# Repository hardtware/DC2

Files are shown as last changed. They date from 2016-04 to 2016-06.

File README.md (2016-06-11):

# DC2 Setup

0. [Unpacking your DC2](#0-unpacking-your-dc2)
1. [Power up your DC2](#1-power-up-your-dc2)
2. [Find the DC2 on your network](#2-find-the-dc2-on-your-network)
3. [Configure the DC2](#3-configure-the-dc2)
4. [Add the DC2 as a docker machine](#4-setup-dc2-as-a-docker-machine)
5. [Assemble the DC2](#5-dc2-assembly)
6. [FAQ](#6-faq)

## 0. Unpacking your DC2

- The first time you open the container doors, be really careful. The container is a model and was not designed to be an enclosure. If a hinge breaks, you can set it aside. If you have success gluing your hing back on, please share.

- We booted all of the MinnowBoard Turbots to make sure they would cleanly boot. See the FAQ below if your MinnowBoard does not boot up.

## 1. Power up your DC2

1. Let's make sure your MinnowBoard boots up and get it all setup while we can easily see the lights etc. before putting it in the container. If you have more than one DC2, let's set them up separately.

2. Set your MinnowBoard on the pink foam to protect it from shorting out.

3. Connect your USB drive to the MinnowBoard. Plug it into the USB socket that is blue.

4. Connect your MinnowBoard with an ethernet cable to the same network your PC that you will use to setup the DC2 is connected to.

5. OPTIONALLY connect your MinnowBoard to a display with a micro HDMI connector.

6. The last connection will be connecting your MinnowBoard to power.

7. You should see the USB drive light flicker. If you have an display connected, you should see the the boot sequence scroll across.

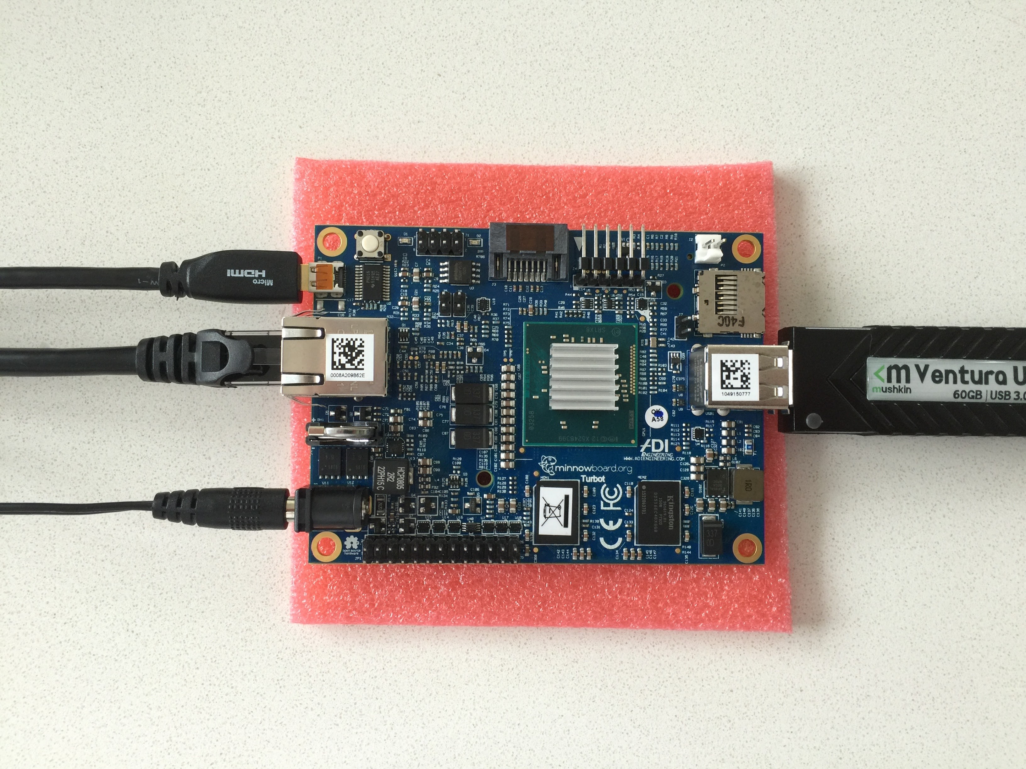
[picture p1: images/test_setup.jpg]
test setup
    

## 2. Find the DC2 on your network

1. Make sure you have Bonjour / mDNS.

    When you connect your DC2 to your network, it will be using DHCP to get an IP address. To work with the DC2 from other machines, we will need to find out where it is. The DC2 will default to having the '''dc2.local''' hostname which will be broadcast with mDNS aka Bonjour. If you have a Mac or Windows 10 machine, you are good to go. If you have an earlier version of Windows, you will need to install [Bonjour Services](https://support.apple.com/kb/DL999?viewlocale=en_US&locale=en_US), If you are on a linux box, you can install [Avahi](https://wiki.archlinux.org/index.php/Avahi).

2. If you have more than one DC2, then set them up one at a time so you can change the host names to differentiate between them.

3. Check you can connect to your DC2.

    Open up [http://DC2.local:8765](http://DC2.local:8765) with your browser -- this should return the configuration information from your DC2.

    It can take 40 seconds for the DC2 to boot, and 30 seconds for the dc2-node script to run and Bonjour to have completed its broadcast so that loading the web page to work. You should see something like this:

    ```json
    {
        "latestVersion": "1.0.4",
        "version": "1.0.4",
        "hostname": "dc2",
        "ip": "a.b.c.d",
        "MAC": "ff:ff:ff:ff:ff:ff",
        "callHomeResponse": 200
    }
    ```

    Where `a.b.c.d` is the IP address of your DC2 and `ff:ff:ff:ff:ff:ff` is the MAC address of your DC2 ethernet port.

## 3. Configure the DC2

1. Check that you can SSH into your DC2.

    - `username`: `jack` is the preconfigured username
    - `password`: `hardtware` is the preconfigured password

    ```shell
    ssh jack@dc2.local
    ```

2. Change your password

    ```shell
    passwd
    ```

    Enter `hardtware` for the old password, and then enter your new password.

3. If you don't have an ssh key, on *another* machine run the following:

    ```shell
    ssh-keygen -b 4096 -f ~/.ssh/id_rsa.dc2
    ```

    You will be prompted to create a passphrase, create one and enter it in twice as prompted.

4. Copy your SSH public key to your DC2.

    First `exit` your SSH session with your DC2.

    If your SSH public key is at `~/.ssh/id_rsa.pub` (if created above, use `~/.ssh/id_rsa.dc2`) then from your machine:

    ```shell
    ssh jack@dc2.local "cat >> .ssh/authorized_keys" < ~/.ssh/id_rsa.pub
    ```

    Enter your new password when prompted.

    You should now be able to `ssh jack@dc2.local` and not be prompted for a password.

5. If you are not in the `America/Los Angeles` timezone you can change it with:

    ```shell
    sudo dpkg-reconfigure tzdata
    ```

6. If you want to change the locale, follow directions at [https://help.ubuntu.com/community/Locale](https://help.ubuntu.com/community/Locale).

7. If you have more than one DC2, change your hostname by replacing `dc2` to a new hostname unique on your network (eg. dc2a, dc2b, dc2c) in the `/etc/hostname` and `/etc/hosts` files.

    For example, if you wanted to change the hostname to `dc2a`, you would run:

    ```shell
    sudo echo dc2a /etc/hostname
    sudo sed -i 's/dc2/dc2a/1' /etc/hosts
    ```

    Then restart `hostname` and `avahi` services with:

    ```shell
    sudo service hostname restart
    sudo /etc/init.d/avahi-daemon restart
    ```

    > NOTE: Everwhere you see `dc2` below, change that to the new hostname you have given your DC2.

8. OPTIONALLY change the username from `jack` to something else. This requires a few more commands and should be considered a bit more advnaced of a topic.

    In our example we will change the username to `bob` and remove `jack` entirely. For this example, start my being logged in as `jack`.

    Create the new user:

    ```shell
    sudo useradd -m bob
    ```

    Set a `sudo` password for the user:

    ```shell
    sudo passwd bob
    ```

    Create the `ssh` directory for the user:

    ```shell
    sudo mkdir /home/bob/.ssh
    sudo chown bob:bob /home/bob/.ssh
    sudo chmod 700 /home/bob/.ssh
    ```

    If you created and copied over a ssh key for jack, let's copy it over to bob.

    ```shell
    sudo cp /home/jack/.ssh/authorized_keys /home/bob/.ssh/authorized_keys
    sudo chown bob:bob /home/bob/.ssh/authorized_keys
    ```

    The last item is to add `bob` to all of the appropriate groups that `jack` is a member of:

    ```shell
    sudo usermod -a -G adm bob
    sudo usermod -a -G cdrom bob
    sudo usermod -a -G sudo bob
    sudo usermod -a -G dip bob
    sudo usermod -a -G plugdev bob
    sudo usermod -a -G lpadmin bob
    sudo usermod -a -G dc2 bob
    sudo usermod -a -G sambashare bob
    ```

    In a new terminal window, try to SSH now as bob using pubkey auth:

    ```shell
    ssh -o IdentityFile=~/.ssh/id_rsa bob@dc2.local
    ```

    > NOTE: You will need to change `~/.ssh/id_rsa` to your respective key path from above and `dc2.local` to whatever you changed your hostname to above as well.

    If you are able to SSH in at this point you have correctly created another user and setup their SSH key correctly.

    As the final step, you may remove the `jack` user from the device.

    ```shell
    sudo userdel -r jack
    ```

9. OPTIONALLY disable password authentication and only allow pubkey authentication. This is recommended for most users but is considered optional because it is more advanced.

    Bring up `/etc/ssh/sshd_config` in your favorite editor and uncomment the line that has `PasswordAuthentication`. Change the value to `no` if it is not set as such.

    Once completed, run:

    ```shell
    sudo service ssh restart
    ```

10. OPTIONALLY update your packages.

    Run:

    ```shell
    sudo apt-get update
    sudo apt-get upgrade
    ```

    You may need to enter `y` to approve the updates.

## 4. Setup DC2 as a Docker Machine

1. Make sure you have the [Docker Toolbox](https://www.docker.com/products/docker-toolbox) intalled on your computer.

2. Find the IP address of your DC2:

    ```shell
    ping dc2.local
    ```

    Substitute `a.b.c.d` in the following commands with your DC2's IP address

3. Check that you can use SSH against your IP address:

    ```shell
    ssh dc2@a.b.c.d
    ```

   If you had previously used SSH against that IP address, your will likely get an error and you will need to update your `known_hosts` file.

4. Add your SSH key to your agent.

    ```shell
    ssh-add ~/.ssh/id_rsa
    ```

    You will be prompted for your SSH key passphrase. You may need to change `~/.ssh/id_rsa` to the path of your key that you created.

5. OPTIONALLY create a separate user to run `docker`. This is a security measure.

    On the DC2, create a user and password for the user:

    ```shell
    sudo useradd -m dockeradmin
    sudo passwd dockeradmin
    sudo mkdir /home/dockeradmin/.ssh
    sudo chown dockeradmin:dockeradmin /home/dockeradmin/.ssh
    sudo chmod 700 /home/dockeradmin/.ssh
    ```

    Back on your machine, create a SSH key and copy it to the DC2. Make sure *not* to enter a passphrase for this user, unlike your SSH key pair which most certainly should have a passphrase.

    ```shell
    ssh-keygen -b 4096 -f ~/.ssh/id_rsa.dc2.docker
    ```

    With your favorite editor, create `/home/dockeradmin/.ssh/authrorized_keys` to contain the public half of the keypair (`~/.ssh/id_rsa.dc2.docker.pub`). And make sure to set the proper permissions:

    ```shell
    sudo chown dockeradmin:dockeradmin /home/dockeradmin/.ssh/authorized_keys
    sudo chmod 600 /home/dockeradmin/.ssh/authorized_keys
    ```

    Give the ability to this user full `sudo` access:

    ```shell
    sudo visudo
    ```

    Copy/paste the following towards the bottom after the `%sudo` definition:

    ```shell
    # Docker
    dockeradmin     ALL=(ALL) NOPASSWD: ALL
    ```

    If everything was done perfectly, you should now be able to SSH as this user to the DC2.

    ```shell
    ssh -o IdentityFile=~/.ssh/id_rsa.dc2.docker dockeradmin@a.b.c.d
    ```

6. Setup the DC2 as a generic machine:

    ```shell
    docker-machine create --driver generic --generic-ssh-user=jack --generic-ip-address=a.b.c.d dc2
    ```

    You may need to change the username if you created a separate one above. This command takes a while as it will be updating the DC2. It will create add your DC2 as a machine to run containers in. Sometimes `docker-machine` emits an error about certs.

    An example successful command and output might look like the following (with a couple more options):

    ```shell
    docker-machine create --driver generic --generic-ssh-user dockeradmin --generic-ssh-key ~/.ssh/id_rsa.dc2.docker --generic-ip-address 10.1.12.2 --generic-ssh-port 22 dc2
    ```

    ```
    Running pre-create checks...
    Creating machine...
    (dc2) Importing SSH key...
    Waiting for machine to be running, this may take a few minutes...
    Detecting operating system of created instance...
    Waiting for SSH to be available...
    Detecting the provisioner...
    Provisioning with ubuntu(upstart)...
    Installing Docker...
    Copying certs to the local machine directory...
    Copying certs to the remote machine...
    Setting Docker configuration on the remote daemon...
    Checking connection to Docker...
    Docker is up and running!
    To see how to connect your Docker Client to the Docker Engine running on this virtual machine, run: docker-machine env dc2
    ```

7. Check the status of your DC2 docker machine:

    ```shell
    docker-machine status dc2
    ```

    It should state `Running` at this point.

8. Setup the DC2 as your docker machine:

    To view the environment for your docker machine:

    ```shell
    docker-machine env dc2
    ```

    It should output several lines.

    For assistance with this or any `docker` command you can always run `docker-machine help <command>`.

    Where command can be `env` or any other `docker-machine` command.

9. Run the hello-world container:

    First, you need to setup your local environment by running the above `env` command. The output of that command at the end should have something like:

    ```shell
    # Run this command to configure your shell:
    # eval $(docker-machine env dc2)
    ```

    Run the `eval ...` command.

    After that, run:

    ```shell
    docker run hello-world
    ```

    You should see "Hello from Docker" along with various other output. You now have a functining Desktop Computer Container!

10. Shutting down your DC2. Make sure you properly shutdown your DC2 so that the file system does not get corrupted. If it does, you will need to connect a monitor and keyboard to fix the errors on boot.

    ```shell
    ssh jack@dc2.local
    sudo shutdown -h now
    ```

    Success! Disconnect power, ethernet and HDMI (if connected) and finish assembly.

## 5. DC2 Assembly

1. Connect the MinnowBoard Turbot to the faceplate.

    1. Get a #1 (or #2 if need be) philips head screwdriver and screw the 2 M3 philips screws each in a few turns. You want the screws to go in from the left side if you are looking at the front of the faceplate. We are doing this to loosen the threads as the faceplate threads are 3D printed.

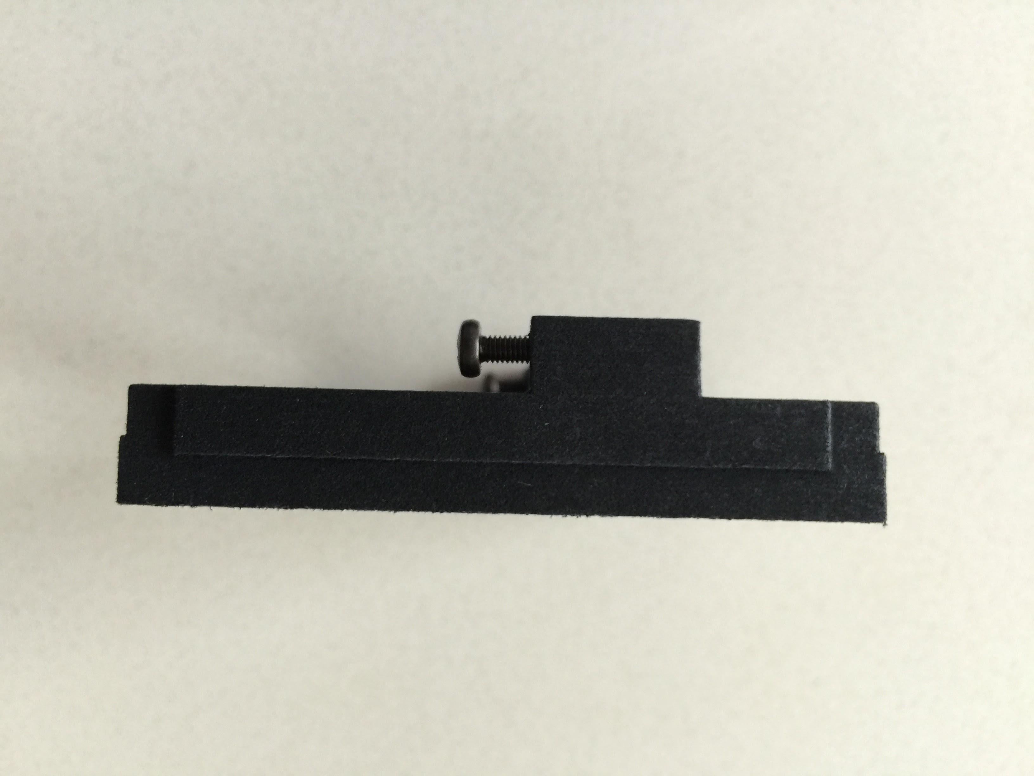
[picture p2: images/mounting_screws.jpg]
mounting screws
        

    2. Take out the screws, set the MinnowBoard Turbot on the faceplate, and screw the screws back in. Tighten enough that the MinnowBoard Turbot does not wobble around on the faceplate. If you have ordered a SilverJaw Lure, you can first mount it to the MinnowBoard Turbot placing the spacers between the two boards, then screw the screws into the faceplate, and then screw the screws into the standoff at the other end of the boards.

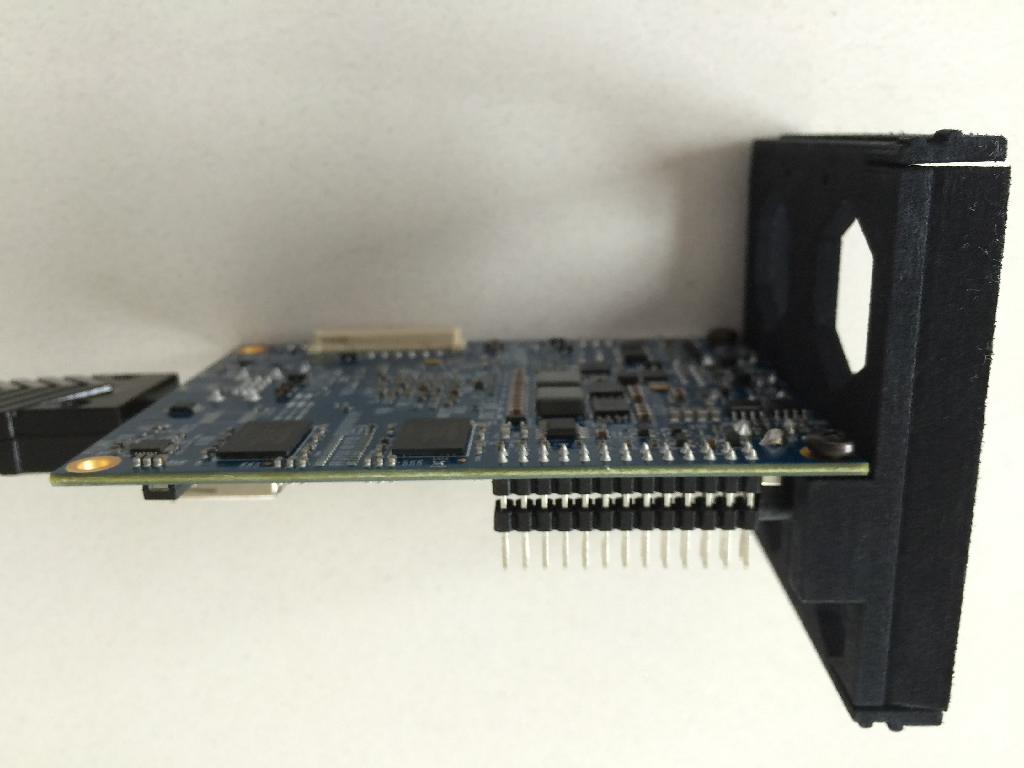
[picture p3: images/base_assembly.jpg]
        

        With SilverJaw

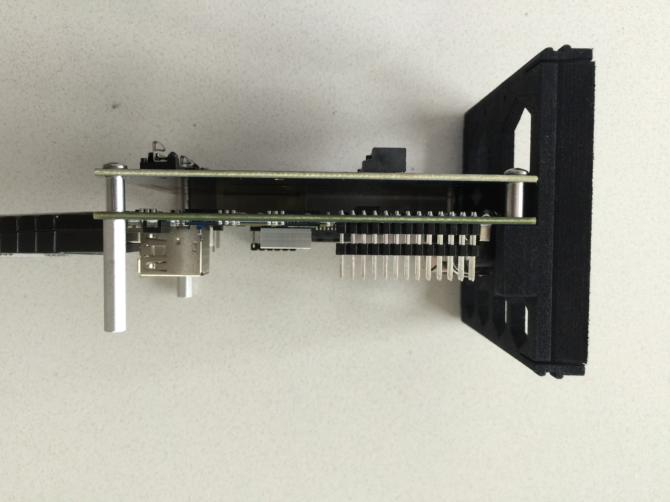
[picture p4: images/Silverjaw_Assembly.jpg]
        

2. Connnect the USB drive to the MinnowBoard if it is not connected.

3. If you have an OLED you need to connect it before installing the MinnowBoard Turbot into the container.

    1. Just as we did with the screws for mounting the MinnowBoard, we need to clean out the threads for the OLED mount. Screw the M1.6 screws into the OLED mounting locations with the supplied allen wrench, and then take them back out.

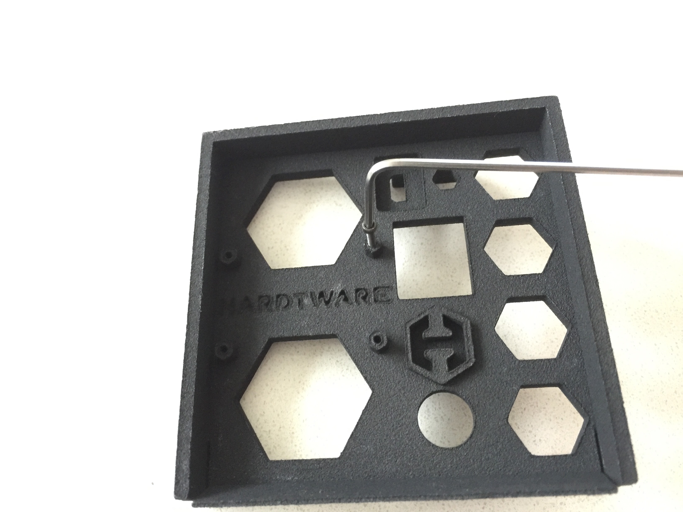
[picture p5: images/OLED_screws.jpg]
mounting screws
        

    2. Insert the memory card into the OLED. This image also shows how the cable will be connected.

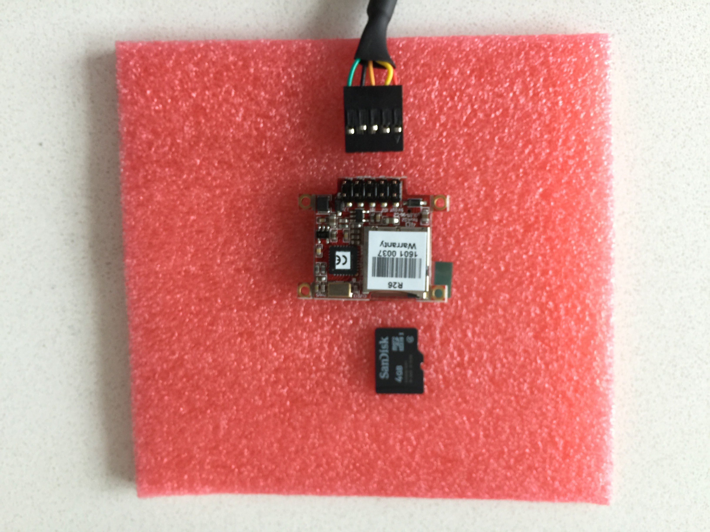
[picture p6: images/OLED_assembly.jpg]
        

    3. Mount the OLED with the 4 M1.6 hex head screws.

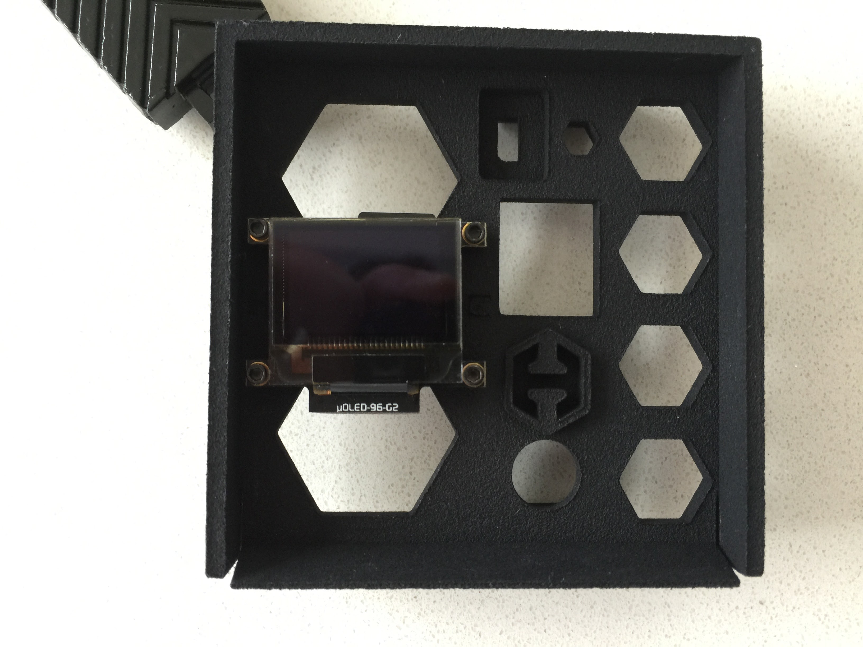
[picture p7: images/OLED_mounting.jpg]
mounting screws
        

    4. Connect the cable from the USB 2.0 connector to the OLED. Make sure you connect per the image and then coil the cable as indicated. You can use the twist tie from the power supply to hold the OLED cable.

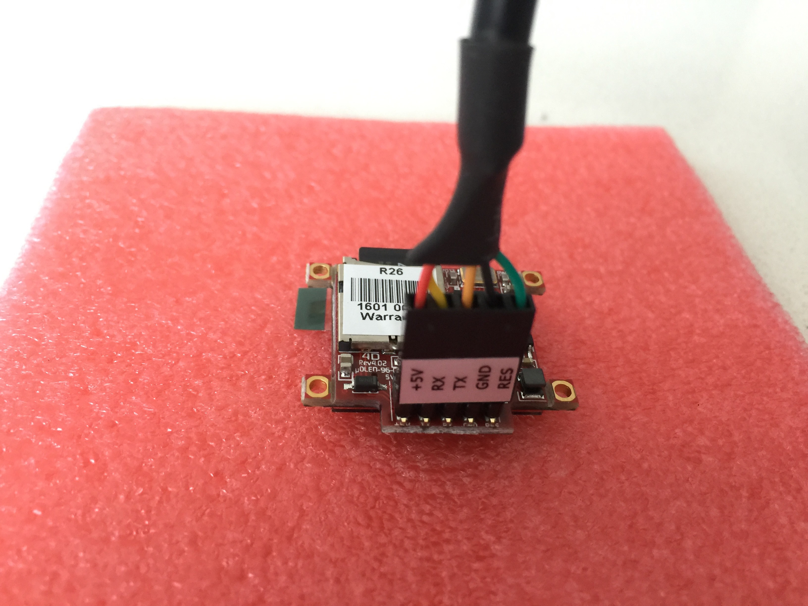
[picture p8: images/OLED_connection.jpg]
        

        Full Assembly

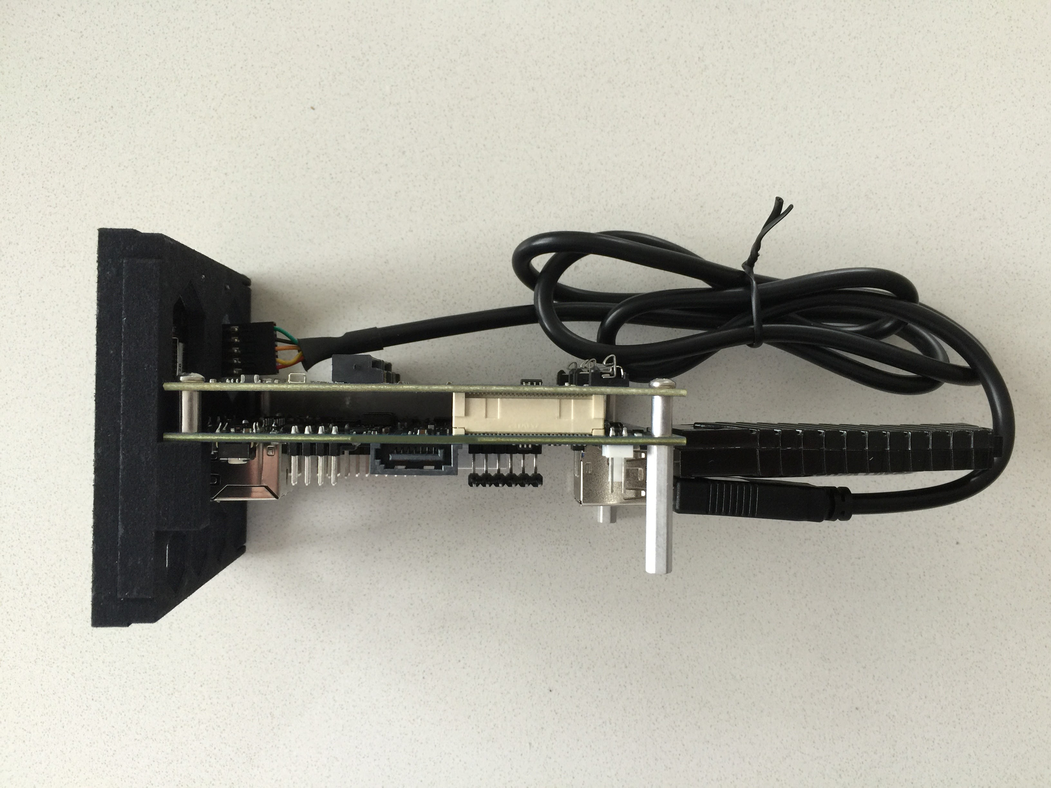
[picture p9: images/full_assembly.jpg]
        

    5. NOTE: we are still working on software to drive the OLED.

4. Slide the assembled MinnoBoard and faceplate into the container. It should click a little when fully installed.

6. Reconnect ethernet and power and enjoy your DC2!

## 6. FAQ

1. **Question**: Something is not working?

    **Answer**: Check the FAQ below. If not answered, file an issue at https://github.com/hardtware/DC2/issues

2. **Question**: What is the CR1225 battery for?

    **Answer**: It is a spare battery. Your MinnowBoard Turbot should have a CR1225 battery in it already.

3. **Question**: I see `WRITE SAME failed. Manually zeroing.` on boot. What is happening?

    **Answer**: You don't need to worry about this and can ignore it. If you would like to make this message go away since it is unrelated to this hardware (it has to do with SCSI driver which is irrelevant for us), you can! Copy the following script to `/usr/local/sbin/disable-write-same`:

    ```shell
    #! /bin/sh
    # Disable SCSI WRITE_SAME, which is not supported by underlying disk
    # emulation.  Run on boot from, eg, /etc/rc.local
    #
    # See http://www.it3.be/2013/10/16/write-same-failed/
    #
    # Written by Ewen McNeill <ewen@naos.co.nz>, 2014-07-17
    #---------------------------------------------------------------------------

    find /sys/devices -name max_write_same_blocks |
        while read DISK; do
            echo 0 >"${DISK}"
        done
    ```

    And then add a call on boot to this script before the `exit` in `/etc/rc.local`.

    On reboot you should no longer see this message.

    Source [link](http://ewen.mcneill.gen.nz/blog/entry/2014-07-17-mininet-on-ubuntu-14.04-in-kvm/).

4. **Question**: The machine did not boot. What happened?

    **Answer**: Sometimes something gets out of sync somewhere with the onboard memory and the drive and Ubuntu thinks something is corrupted and you have to tell it to continue. If you have a display attached you can see it. You can just hit `i` to ignore and everything will be fine. You might need to hit `i` a few times. If you don't have a monitor, try connecting a USB keyboard and hit `i` a few times. If you see the drive light flash, you should be booting.

5. **Question**: How do I remove the faceplate once I have assmebled it?

    **Answer**: To take out the faceplate and the board, put your fingers in the large hex holes, push the faceplate down towards the bottom of the container as the top of the faceplate hooks to the top inside of the container, then wiggle and pull to get it out.

6. **Question**: How can I stack up my containers?

    **Answer**: [remonlam](https://github.com/remonlam) has created an STL you can 3D print to stack up your containers [here](./stacker.md)

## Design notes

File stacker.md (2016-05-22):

# DC2 Stacker

... thanks to [remonlam](https://github.com/remonlam)

The Kickstarter backers that have bought the DC2 Data Center (a stack of 4 containers) might have a hard time to get them stacked.
This is because there's no lock to get the containers nicely stacked. To make sure they keep "stacked" on top of each other I created a small frame called the "DC2 Stacker" :-)

All you need to do is print (a 3D printer that is, not you're regular printer) the [STL file](./sources/dc2_stacker.stl) three (3x) times. One would be the base layer, and the two other layers should be glued together (with superglue) to form the mid section.

The end result should look like this;

#### Place the layer on top of the fist two containers
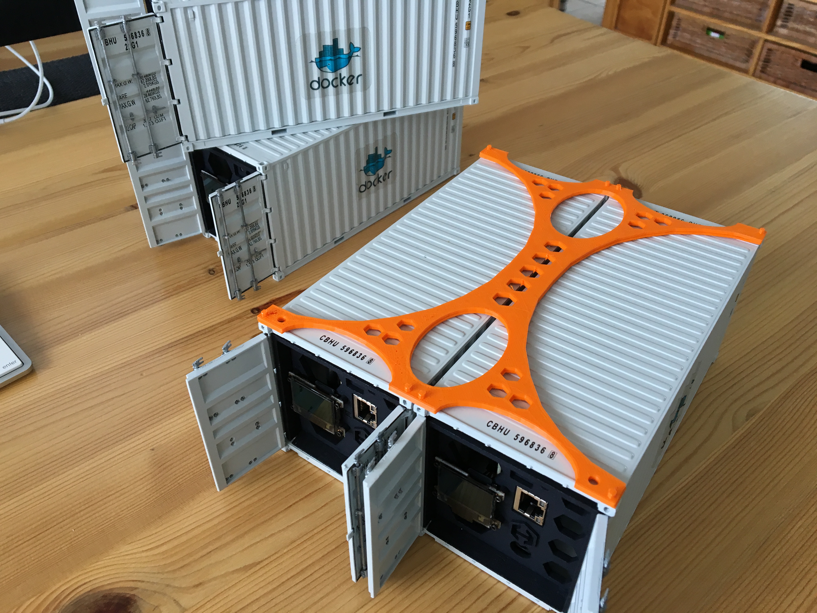
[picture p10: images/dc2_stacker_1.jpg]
Two layers glued together


#### The next layer of containers should fit in nicely
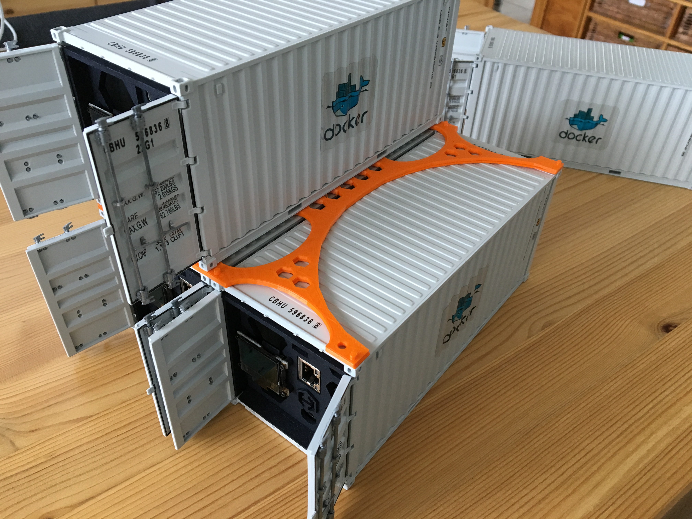
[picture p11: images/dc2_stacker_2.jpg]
Build the stack


#### The end result, now the containers won't fall off the stack
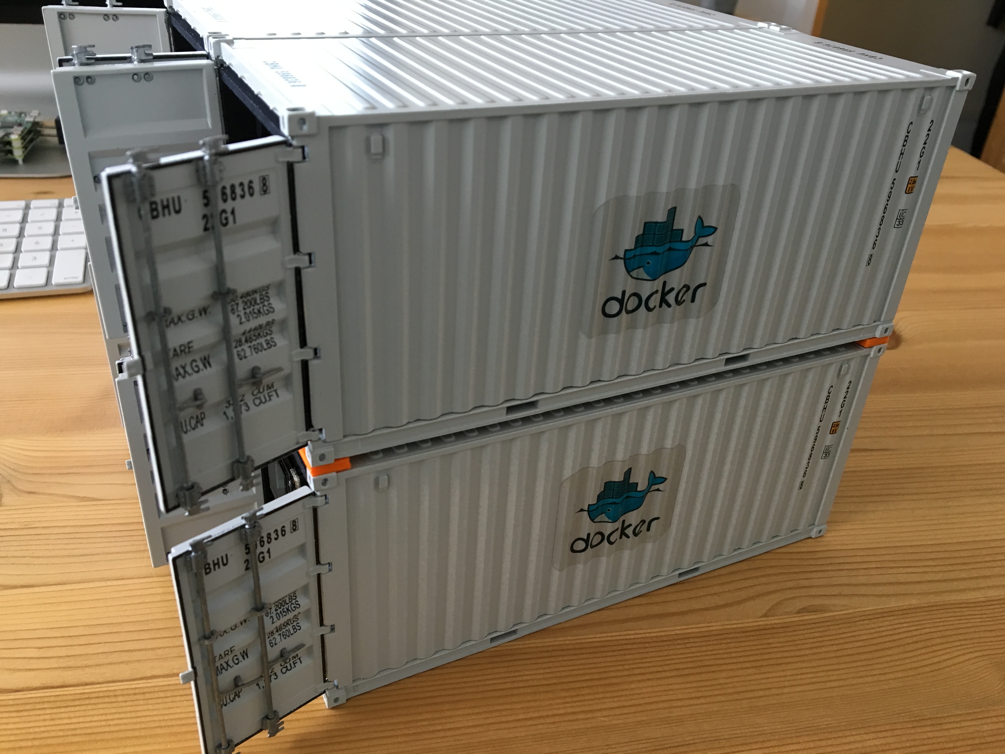
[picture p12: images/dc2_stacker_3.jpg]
End result 1

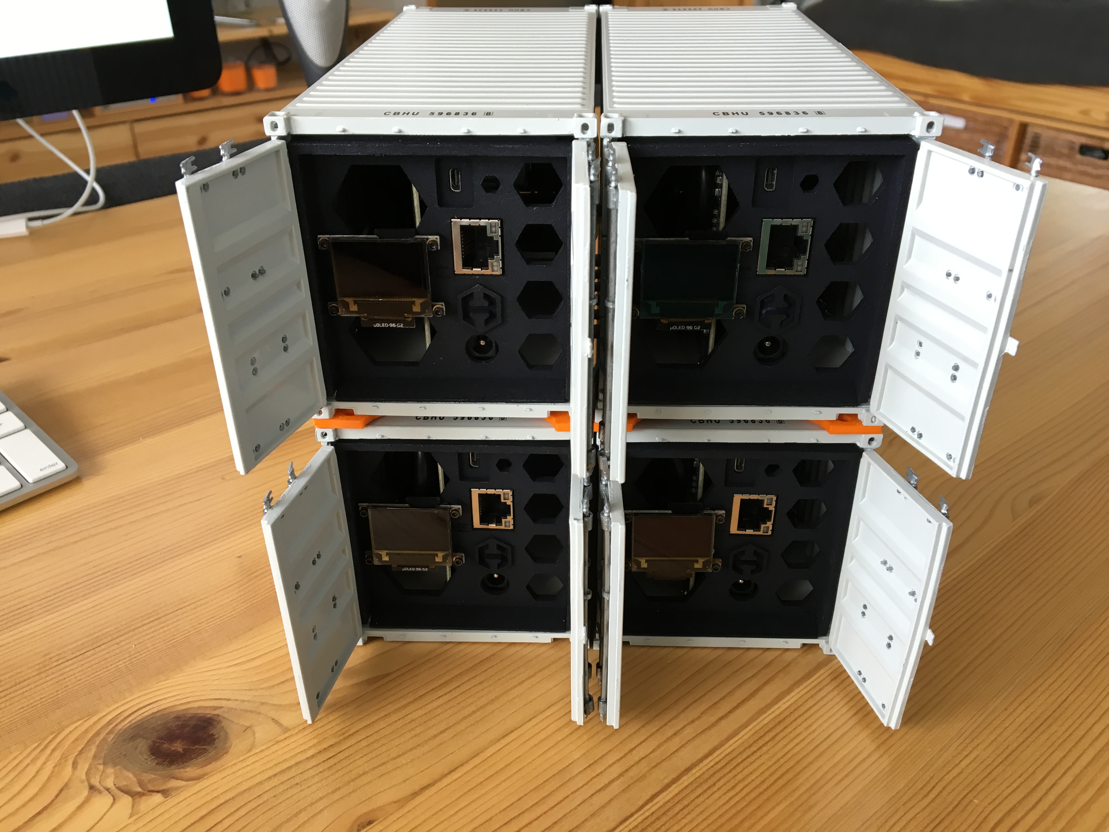
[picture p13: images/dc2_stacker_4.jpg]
End result 2


#### STL file
[DC2-Stacker STL file](./sources/dc2_stacker.stl)

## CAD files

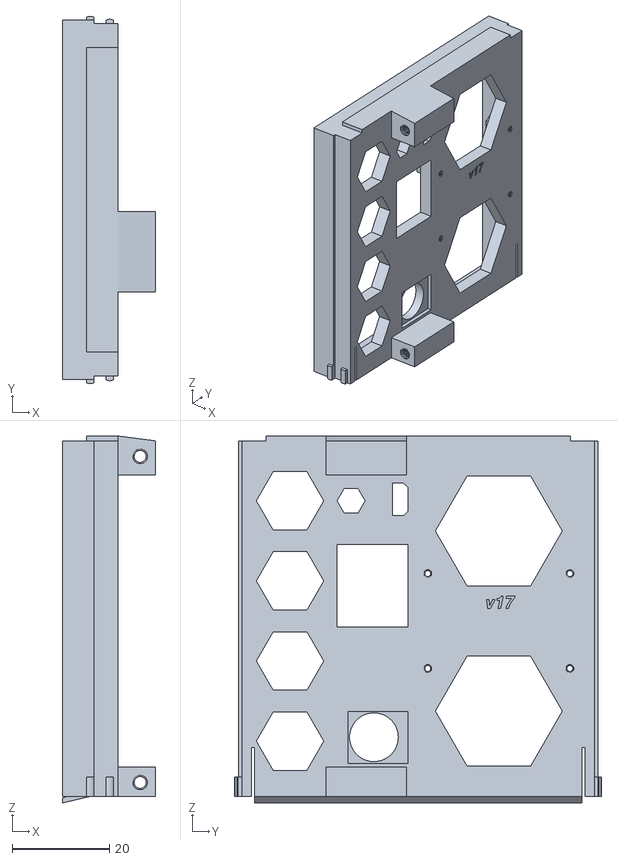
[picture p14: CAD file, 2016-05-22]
sources/FaceplateV17.stl
19.2 x 75.5 x 75.4

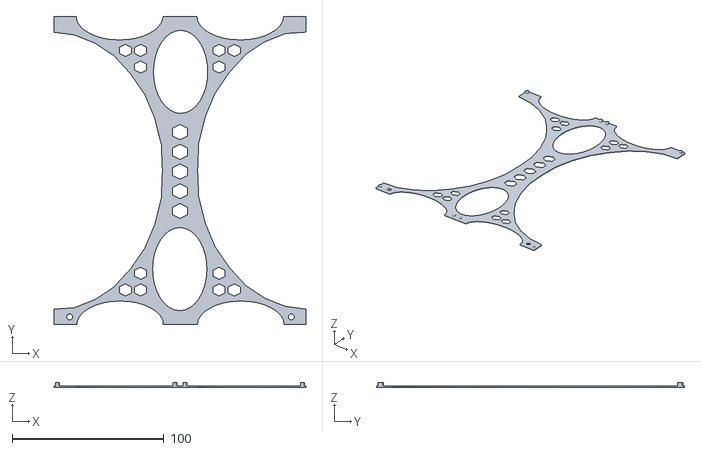
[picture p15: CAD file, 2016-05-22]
sources/dc2_stacker.stl
166.2 x 203.2 x 3.00

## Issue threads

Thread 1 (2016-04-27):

Accidentally broke doors of container off

Xe, 2016-04-27:
Is there any way I can get that repaired?

remonlam, 2016-04-28:
Can't you fix it with glue?

jlhawn, 2016-04-28:
Here's a picture of the first one that I opened. One of the hinges broke after opening the door about 45 degrees:

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

The other door opens just fine and swings out about 135 degrees. I don't want to open it any further than that.

> Can't you fix it with glue?

Is there a particular kind of glue that you recommend? I'm not 100% sure what kind of material this is. I remember reading somewhere that it was zinc.

dickhardt, 2016-04-28:
Unfortunately the doors hinges are fragile.
When opening the doors for the first time, one needs to be really carefully.
I'm sorry your door broke.

dickhardt, 2016-04-28:
I've updated the instructions to warn people.

jlhawn, 2016-04-28:
After trying again to carefully open the door, the top hinge popped off too.

It looks like the pin was misaligned the whole time so it probably never would have been able to open. You can see how it's pointing outward rather than parallel with the other hinges:

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

remonlam, 2016-04-28:
Whoops, that's not going to be fixed with superglue :-(
Not sure if you can solder zink?...

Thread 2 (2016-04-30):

DC2 doesn't connect to network

emdem, 2016-04-30:
The NICs lights light up but I can't see the MAC/etc connect to my network.

Only option is to get a microHDMI and connect to a monitor?

watkinspd, 2016-04-30:
What computer are you using make the ssh connection to dc2.local?

The instructions explain how dc2.local is using bonjour/avahi which makes the dc2.local hostname discoverable on your home network if the dc2 is booting and getting an address from DHCP.

If you are new to setting up and running machines "headless" I'd suggest making the investment in the hdmi cable (and USB connectable keyboard).

emdem, 2016-04-30:
I am using a touchpad S210 running mint (also tried another debian based distro) to connect to dc2.local. My router provides DHCP and when I check, I can see all the MAC addresses/IPs/hostnames of machines I already have but when the DC2 is turned on and connected, nothing. Hard drive light/etc are all on.

remonlam, 2016-05-01:
So just to be clear; you don't see any IP address assignment on your router when you turn on the DC2?
If not perhaps it's easier for troubleshooting to connect an monitor to the minnowboard and check what's going on.

rloura, 2016-05-03:
Same issue as above.  I don't see it show up on the local network, and have not yet sourced an HDMI adapter to see what is going on.

ikenichiro, 2016-05-04:
I'm having the same issue.
As far as I see through the syslog on my network, connections between DC-2 and other hardware seems to be OK, but I get nothing from the DHCP server.
I've ordered the micro-HDMI cable which I should have it by tommorow, and try to see what's going on.

ikenichiro, 2016-05-04:
Solved my issue by connecting a USB keyboard and pressing the button **i** for a few times during the boot. After a few seconds, I got a successful syslog message from the DHCP server. I checked SSH connection (through direct IP address instead of dc2.local ) and it works perfectly.

Since I'm not a linux expert, I couldn't determine what the main cause was, but from the dmesg I see
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
which I suspect might be where the boot might be halting.

I'll also note that maybe this problem occures only at the first boot. Currently I have no problems restarting the system and booting after a shutdown (detaching the power cable for few minutes).

Although, I will try to reproduce the problem after the micro-HDMI cable arrives to see what might be the problem is.

remonlam, 2016-05-04:
@ikenichiro sounds like there's something wrong with the filesystem or at least that's what the system thinks ;-) did you check what date/time the machine had on the first boot?

I had the same issue with my MinnowBoard Max (the old one without a RTC) and CoreOS from time to time the system failed to boot and I needed to force a FS check to get the system up and running again.

Can't check because my DC2 is still at the customs :-( but there should be a RTC on the system, right?
If so than it should keep the correct time even without a power source, maybe you could check this out?

ikenichiro, 2016-05-04:
@remonlam I actually did check it.
According to DC2's syslog, the date/time when syslog started on my first boot was set to Nov 22 13:04:40. Before that was Mar 24 16:02:45 .
> Mar 24 16:02:45 dc2 rsyslogd: [origin software="rsyslogd" swVersion="7.4.4" x-pid="845" x-info="http://www.rsyslog.com"] exiting on signal 15.
> Nov 22 13:04:40 dc2 rsyslogd: [origin software="rsyslogd" swVersion="7.4.4" x-pid="839" x-info="http://www.rsyslog.com"] start
(snip)
> Nov 22 13:04:50 dc2 NetworkManager[809]: <info> WiFi hardware radio set enabled
> May 4 11:29:00 dc2 ntpdate[1258]: step time server 91.189.89.199 offset 14160245.250085 sec

And yes, there is an RTC on the system so it does keeps the correct time without a power souce ( I confirmed this by log file as also).
For trying to reproduce the problem, I am planning to do it with removing the battery on the MinnowBoard which should atleast give some clues to whether the problem is actually in the filesystem or looks like that because of the corrupted system time.

hbokh, 2016-05-05:
See #4. I managed to boot from the USB-drive within Virtualbox, set an easy root password and do some debugging.
My DC2 gets an IP-address from my DHCP-server but remains unreachable eg.
The DC2 is booting OK and I can login as root and type some commands "blind".
Booting from DC2 and typing blind `ifconfig -a > file1` and `netstat -rn > file2`.
Next shutting down the DC2 and boot from the USB-drive within Virtualbox so I can read `file1` and `file2` to see what is there.
`file1` shows DC2 has gotten the IP-address my DHCP-server offered; `file2` shows the default gateway for `eth0`. Still the DC2 remained unreachable.
In the meantime I have disabled "network-manager" without result.

Any hints / clues / etc.?

remonlam, 2016-05-05:
@ikenichiro so it changed from March 24 to November 22 and back to the correct time (May 4), that couldn't be ok if it has a working RTC, I'm curious what will happend when you remove the RTC battery.

@hbokh Nice troubleshooting 👍 perhaps you could also try if the node can reach the Internet or your local machine, just a ping would probably do?

hbokh, 2016-05-05:
Everything is working in Virtualbox (incl. node), just not on the MinnowBoard...

In the meantime I have created a script to test all kinds of network related stuff when root logs in (set in `.profile`) and re-enabled network-manager.

/root/test:

```
#!/bin/sh

echo "===========================================================================================" > results
ifquery eth0 >> results
echo "===========================================================================================" >> results
ifconfig -a >> results
echo "===========================================================================================" >> results
ethtool eth0 >> results
echo "===========================================================================================" >> results
netstat -rn >> results
echo "===========================================================================================" >> results
nmcli nm >> results
nmcli d >> results
echo "===========================================================================================" >> results
ping -c3 192.168.178.1 >> results
echo "===========================================================================================" >> results
ping -c1 8.8.8.8 >> results
echo "===========================================================================================" >> results
ping -c1 google-public-dns-a.google.com >> results
```
Fails on the GW-ping at 192.168.178.1.
It seems the DC2 is never able to setup a connection to the default gateway, even when hard-coded with a fixed IP-address; netmask; gateway in `/etc/network/interfaces`.

hbokh, 2016-05-05:
So far I guess the issue is related to the Realtek interface / driver.
But I can't do any debugging anymore without installing a new OS since I kinda "briked" the USB-image with grub... Unless (as stated in #4) I can re-image the 60GB USB-drive from an image.
Until then, this by far the most expensive paper presse I have ever bought :(

remonlam, 2016-05-05:
That's a bummer :-(
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
ikenichiro, 2016-05-06:
Got my HDMI cable and a chance to look around a bit...
@remonlam I detached my power cable for quite a while, and had no problem with the RTC having the right time.
> May  4 14:45:00 dc2 rsyslogd: [origin software="rsyslogd" swVersion="7.4.4" x-pid="565" x-info="http://www.rsyslog.com"] exiting on signal 15.
> May  6 09:25:39 dc2 rsyslogd: [origin software="rsyslogd" swVersion="7.4.4" x-pid="571" x-info="http://www.rsyslog.com"] start

After taking off the battery and re-setting the RTC, I failed to boot a few times. Still not sure why since the display showed nothing.
Unplugging and plugging in the power a few times, I got it booting with display showing. Waited a few seconds to let the boot manager choose the default boot (which is Ubuntu).
The problem is, the moment it choose Ubuntu it showed an message something about an display error, telling it will try to boot showing nothing. The message quickly disappeared so I'll try to get that message next time I try.
Pressing a few i button after that message disappeared helped again, which let me able to login through SSH.
Checking the logs, the RTC had a reset as expected, but this time it was Sep. 17th.

> May  6 09:28:55 dc2 rsyslogd: [origin software="rsyslogd" swVersion="7.4.4" x-pid="571" x-info="http://www.rsyslog.com"] exiting on signal 15.
> Sep 17 17:02:27 dc2 rsyslogd: [origin software="rsyslogd" swVersion="7.4.4" x-pid="820" x-info="http://www.rsyslog.com"] start

I also found the same "EXT4-fs" erros in my syslog, which I'm assuming is caused by the incorrect time, and is the problem that is halting Ubuntu to boot.

hbokh, 2016-05-07:
@ikenichiro No offense, but your issue does not seems to be network-related (anymore).
"Unplugging and plugging in the power a few times" will only give you an unclean filesystem, hence the "EXT4-fs" errors. Incorrect time won't!
Try to shutdown gently if possible. You got a keyboard and display for that.

ikenichiro, 2016-05-08:
@hbokh The problem @emdem, @rloura and I was facing was a little bit different then yours. In your case, your board showed up in your local network (offered IP from DHCP) but in our case it does not. So originally it was thought that it was a network issue, but by trying things out, I'm thinking the cause is not a network issue. Since it is true this issue is going off topic as a "network-related" problem, making this post as my final post in this issue, I might make a different issue if it sill might be an issue to solve.

Last time I needed to unplug an plug the power a few times since I saw nothing on the display and the keyboard wasn't responding, but I completly forgot about the switch on the board near the hdmi interface. Might be slightly better using that switch rather than just unplugging the power.
Although, this time I didn't need to do any of that since the display and keyboard worked.
Still, the boot halts here.
> Starting userspace bootsplash     [OK]
ors were found while checking the disk drive for /boot.
s:Press F to sttempt to fix the errors, I to ignore, S to skip mounting, or M for manual recovery
Starting Send an event o indicate plymouth is up     [OK]
Stopping userspace  bootsplash      [OK]
Stopping Send an event to indicate plymouth is up      [OK]
Starting Bridge socket events into upstart      [OK]

Since it halt's before the nework configuration starts, that's why the device wasn't showing up in the network. Pressing i will let you continue to boot, and I think you will be able to see your DHCP server issuing an IP address to dc2.
So I think @remonlam was right about probably the system is thinking that the filesystem is corrupted which is caused by the wrong date/time.

Finally my answer to this issue is to get a usb keyboard and press i after waiting for a while ( one minute should be more than enough).
Probably this problem will only occur on your first boot incase the RTC had a reset (e.g. changing board battery).
The clock will sync through ntp after the first boot so you won't need to worry about this problem after one successful boot.

To actually solve the issue, forcing FS check on boot might solve the problem. I haven't tried this yet, but since now I know what's happening, I'm thinking to move on with the setup and think about this later.

dickhardt, 2016-05-20:
To confirm the suspicions, somehow the RTC gets confused, and then the OS thinks the file system is corrupt, but it is not. Any suggestions on how to have the OS ignore this error are welcome. We just have told the system to ignore the error and then it boots fine on subsequent boots.

We booted ALL the motherboards and then tested that they would boot again with no keyboard. Looks like that is not a permanent fix.

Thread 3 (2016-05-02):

DC2 can not connect to the network also

tsuitor, 2016-05-02:
I'm also having problems getting my DC2 seen on my network. However, the first time I booted it up, I apparently had an Ethernet cable that went bad. Right now I'm running it headless and using my iMac to try and connect.The board, network and SSD all show lights. Is there something else I can try before getting a mini HDMI cable (and probably a new Ethernet cable...). Thanks

remonlam, 2016-05-03:
I think there is already an issue related to this one. #2

josegonzalez, 2016-05-09:
You'll also need a keyboard. I found mine booted up and didn't connect because the usb stick needed to be "fixed" (aka I had to confirm that it was okay to fix).

tsuitor, 2016-05-09:
Okay, with a keyboard and display, I was able to get this to boot up and connect to the network; and mostly get docker running. However, now I'm getting the following error message when I try docker run:

docker: Error response from daemon: client is newer than server (client API version: 1.23, server API version: 1.22).

This is on a imac that I just installed docker toolbox last week. I'm guessing something is out of sync, but docker-machine upgrade dc2 doesn't seem to help.

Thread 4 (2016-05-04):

Non-reachable device - works in Virtualbox though

hbokh, 2016-05-04:
Received my DC2. My DHCP-server is offering an IP-address, but no PING response after over half an hour too.
I have no option to use a display, so plugged in a USB-keyboard and pressed `i` till my fingers bled. No luck...

Is there an image available to re-image the 60GB USB-drive?

**UPDATE, 12 hrs later**
Next, trying to boot from the USB-drive from within Virtualbox (HOWTO: http://www.sebastien-han.fr/blog/2013/12/16/virtualbox-mac-os-x-10-dot-9-boot-from-an-usb-drive/) and setting "Motherboard" to "Enable EFI" is working and gives me a VM. I can log in with user `jack` etc.

But why isn't it reachable on the network from the MinnowBoard? I'm still investigating.

hbokh, 2016-05-06:
Closed. See #2 for root cause.

Closed 2016-05-06.

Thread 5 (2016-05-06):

OLED doesn't work

emdem, 2016-05-06:

remonlam, 2016-05-08:
Well I have read somewhere that they are working on the code to get the OLED display working.

emdem, 2016-08-09:
anyone made any progress? if not, anyone have docs for the oled display and how to get code on the SD card?

emdem, 2016-08-09:
CP2102 USB to UART Bridge Controller driver + http://www.4dsystems.com.au/product/4D_Workshop_4_IDE/downloads?

emdem, 2017-10-30:
any updates? or anyone else successfully written some code for the oled?

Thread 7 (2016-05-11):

Boot failed

thepatrick, 2016-05-11:
After getting my MinnowBoard out of the container, and removing the USB stick I can boot to the UEFI/BIOS screen. However... when I reattach the USB stick the keyboard stops working inside the UEFI/BIOS interface. As soon as I disconnect it works again.

Now when I boot (with the USB stick attached) it gets through the memory check and then very quickly flashes Boot failed, before taking me to a UEFI interactive shell.

Do I:

* Have a faulty USB stick?
* Where is the image that these drives are flashed with so I can re-flash it / flash another drive to further debug this?

watkinspd, 2016-05-13:
While I was hacking around with building and booting sd-card images and other USB drives I noticed that sometimes it helped to use the Boot Manager option of the BIOS and the reset feature that was listed.
This seemed to cause the bios to re-scan for boot devices such that it would discover the sd-card or the USB drive and the drive partitions on it.

I've managed to get ubuntu, centos7, and coreOS booting on a different USB drive, and from sd-card.  To do this find the bare-metal install instructions for the linux distro you want to spin.  In my case I did not want to blast away the DC2 supplied USB drive image since I'm still hacking around and often landing in a non-bootable state.

I've still got lots of homework to do to learn how the BIOS works and how linux system drives are imaged and booted.

Right now I have the DC2 running centos7 and RedHat Openshift (kubernetes/docker) --- lots of fun.

dickhardt, 2016-05-13:
Some of the MinnowBoards are temperamental and don't always recognize the
USB devices. We found that with a number of boards. We did find that once
it was up and running, it was ok. I would guess that the USB drive and
keyboard are detected, or neither are detected.

Did you check if the USB drive is ok and that it will mount in another
device? We did have one USB that was DOA. If so, we can get you a new USB.

If the USB drive is ok, then I would try restarting a few times to see if
it starts to behave. If not, let's get you a new MinnowBoard.

On Fri, May 13, 2016 at 10:10 AM, Peter Watkins <notifications@github.com>
wrote:

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

--
Subscribe to the HARDTWARE <http://hardtware.com/> mail list to learn about
projects I am working on!

thepatrick, 2016-05-24:
I've dropped a Samsung m.2 SSD into my silver jaw lure & did a plain install of Ubuntu 16.04 server and have had no issues since.

Attempts at getting other devices to recognize the supplied USB stick - my windows pc & mac are both convinced there's nothing there (not even something that I can format)

dickhardt, 2016-05-24:
@thepatrick sorry your drive was DOA. We can send you a replacement.

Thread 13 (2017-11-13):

Ubuntu Rebuild Instructions

tyndyll, 2017-11-13:
I've had to replace the SSD. Is it possible to get instructions to rebuild a new disk?

remonlam, 2017-11-13:
I don't think that it has ever been published, however if you need a copy of the image? please let me know...

dickhardt, 2017-11-14:
Here are the directions I got from my friend that built the image

1. grab the ubuntu-desktop x86_64 14.04 LTS ISO
2. install it onto another usb drive, not the DC2 one, using one of the ubuntu USB media installers (either from w/in another ubuntu box, or there’s a windows media prep tool, or something else. http://www.ubuntu.com/download/desktop/create-a-usb-stick-on-ubuntu )
	** Note that step #2 was not easy, especially when I was using the ubuntu-server ISO instead of the desktop. Desktop ISO worked much better, but I’m not sure all the media prep programs on that page above are bug free. **

3. all defaults during the install, hostname is “dc2”, username is “dc2” i wrote down that the pw was “ubuntu” but I think you changed the default username and password. I enabled automatic security updates (again, I think this is probably the default setting).
4. this should set up a dhcp by default, I don’t think I enabled IPv6 or if I did I just left it as defaults
5. no special packages during install
6. On first boot my notes say I installed packages for docker and node. I don’t know if I needed to install the bonjour stuff (avahi-* packages) or if I was already enabled by default. I don’t know if I needed to enable docker or node to run on boot, but that would be another command to enable it on boot ( http://askubuntu.com/questions/9382/how-can-i-configure-a-service-to-run-at-startup explains).
7. I disabled the X11/graphical boot (using these instructions http://www.htpcbeginner.com/force-ubuntu-boot-into-terminal/ )
8. I manually updated all packages (“sudo apt-get update ; sudo apt-get upgrade ; sudo apt-get dist-upgrade ; sudo apt-get autoremove”) then reboot if it installed a new kernel, or if it says to reboot.
9. I probably installed the openssh-server package (“sudo apt-get install openssh-server”).
10. I did some checks on the permissions of the .ssh directory to make sure we’d be able to ssh in, then tested it from remote (“ssh dc2@dc2.local”).
11. I did some final cleanup (removing files I had created, .git dirs, .bash_history, etc… but this isn’t necessary unless you’re re-creating a new gold image).

tyndyll, 2018-01-16:
Finally got round to trying this. There seems to be something weird with the EFI boot - it seems like it is expecting a certain GUID for the disk (as set up in the boot options under the name ubuntu)

Would it be possible to get the original image

tyndyll, 2018-01-25:
@remonlam Would it be possible to get a copy of the image?

remonlam, 2018-01-25:
@tyndyll sure let me find a way to share it

remonlam, 2018-01-25:
Hope this one works!
https://we.tl/DnDh3lStUA

Closed 2017-11-14.

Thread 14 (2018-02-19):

New Minnowboard

MadDucks, 2018-02-19:
A family member of mine had been moving my DC2 without me knowing it, and plugged it into 12v.  The magic smoke came out.

Can I grab: https://www.mouser.com/ProductDetail/ADI-Engineering/MBT-2210/?qs=kWQV1gtkNnfue4gk0ao8Xg%3d%3d  and have it work with the faceplate and the USB drive?

dickhardt, 2018-02-19:
That and https://minnowboard.org/minnowboard-turbot/ look to be the same.

When the Turbot came out, we found there was a little bit of difference in
placement of the power supply, so hopefully these have the same alignment
as the ones we had.

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

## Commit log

2015-12-24 Create assembly
2015-12-24 Update and rename assembly to assembly.md
2016-05-15 Added STL file
    [dc2_stacker.stl]
2016-05-15 Link to STL file
2016-05-22 add in STL for faceplate
    [FaceplateV17.stl]
